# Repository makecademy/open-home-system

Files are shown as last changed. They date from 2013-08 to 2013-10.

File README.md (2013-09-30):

open-home-system
================

Repository for the Open Home System (OHS) modules & software. The repository is organized as following:

- Hardware: all the devices included in the Open Home System. For each device, you will find Arduino sketches (to test the module & connect it to the whole system) and 3D files for the cases.
The folder common contains the common files used for Open Home System, like the Arduino library, the primitives for the cases, and the schematic & layout for the Open Home System board.

- Software: all the software you need to run Open Home System.

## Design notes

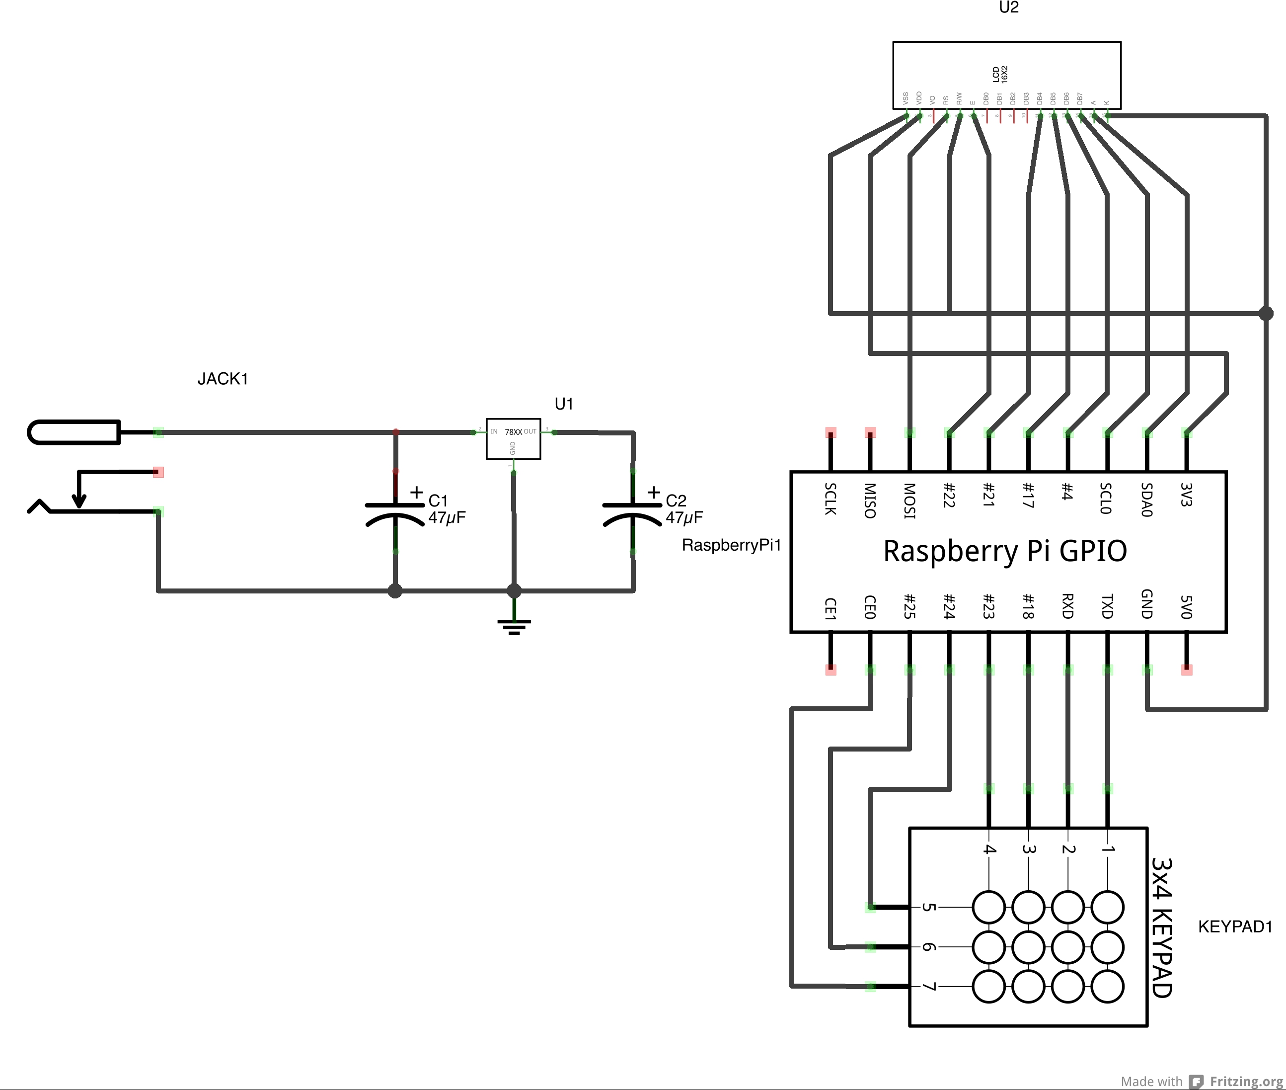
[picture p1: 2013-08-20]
hardware/base/pcb/base_station_schem.jpg

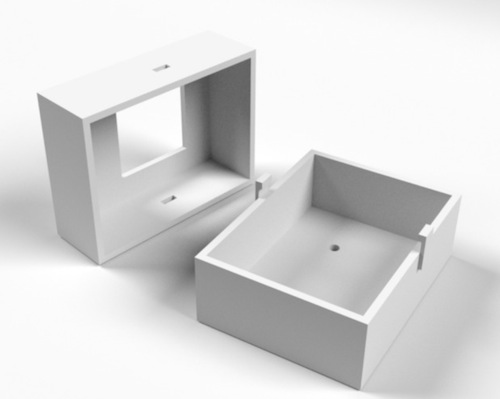
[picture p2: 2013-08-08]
hardware/motion/case/render.jpg

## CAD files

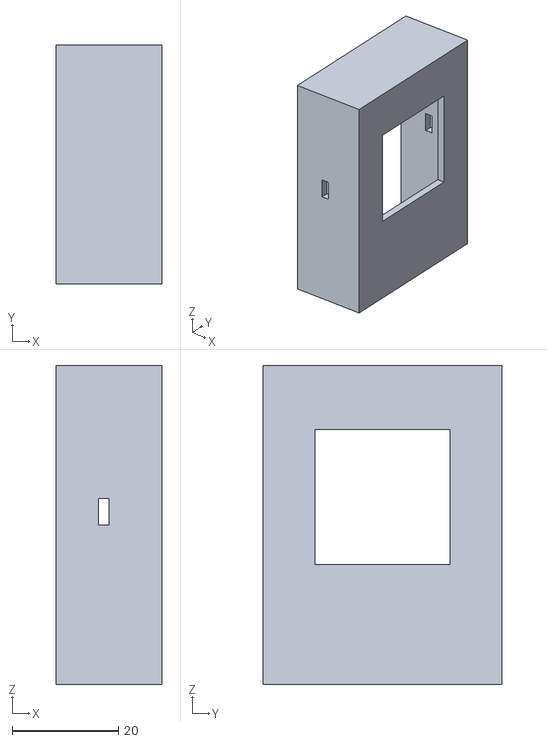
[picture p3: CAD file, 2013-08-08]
hardware/motion/case/motion_front.stl
20.0 x 45.0 x 60.0

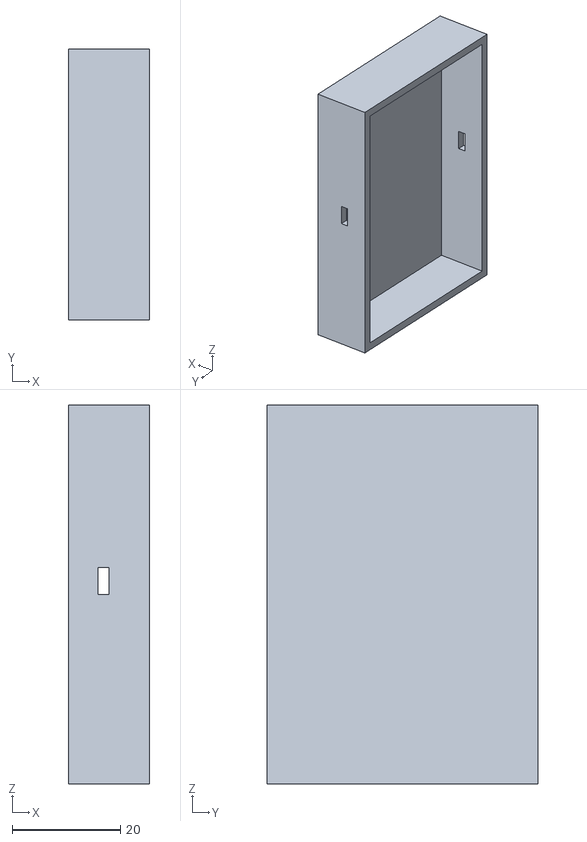
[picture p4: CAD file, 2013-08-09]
hardware/temperature/case/temperature_front.stl
15.0 x 50.0 x 70.0

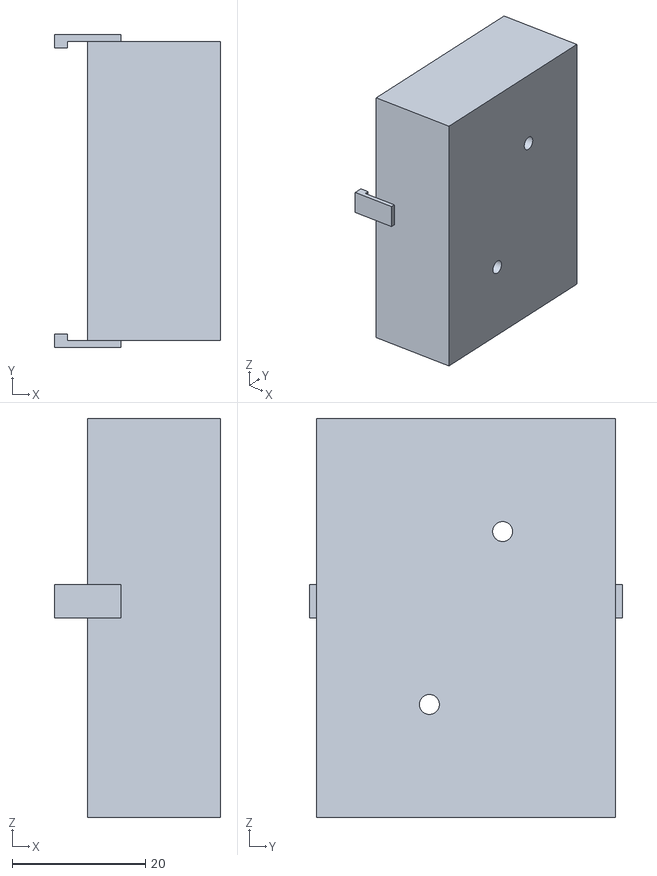
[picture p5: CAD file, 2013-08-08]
hardware/motion/case/motion_back.stl
25.0 x 47.0 x 60.0

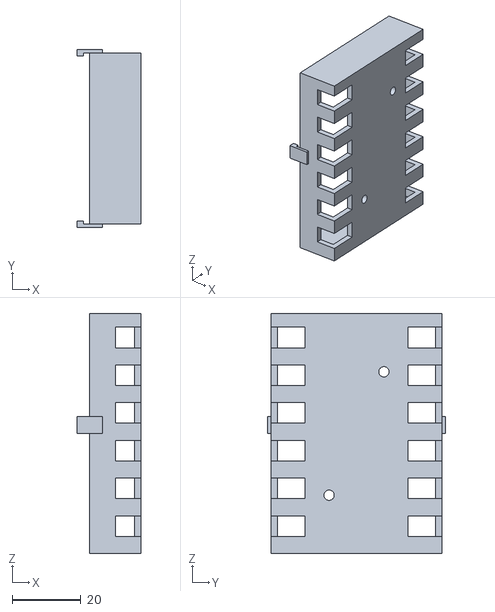
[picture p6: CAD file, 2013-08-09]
hardware/temperature/case/temperature_back.stl
18.8 x 52.0 x 70.0

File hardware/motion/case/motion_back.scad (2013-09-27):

// Use common library
use <../../common/primitives.scad>;

// Parameters

// Main box
w = 60;
l = 60;
h = 15;
thickness = 2; 

// Batteries
battery_h = 49;
battery_r = 7;
number_batteries = 3;
draw_batteries = 1;

// Holes
fixation_hole_r = 1.5;
distance_from_edges = 15;

// Attach
attach_clip_h = 1;
attach_clip_l = 2;
attach_l = 2*(5+attach_clip_l);
attach_w = 5;
attach_h = 1;


// Back box
difference(){

	case(h, w, l, thickness);

	case_hole(distance_from_edges,distance_from_edges, fixation_hole_r);
	case_hole(w-distance_from_edges,l-distance_from_edges, fixation_hole_r);

}

// Attach
translate([-attach_l/2,-attach_h,l/2]) cube([attach_l,attach_h,attach_w]);
translate([-attach_l/2,0,l/2]) cube([attach_clip_l,attach_clip_h,attach_w]);

translate([-attach_l/2,w,l/2]) cube([attach_l,attach_h,attach_w]);
translate([-attach_l/2,w-attach_h,l/2]) cube([attach_clip_l,attach_clip_h,attach_w]);

// Batteries
if (draw_batteries == 1) {
	batteries(w,l,6,battery_r, battery_h, number_batteries);
}

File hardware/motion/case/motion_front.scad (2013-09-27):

// Use common library
use <../../common/primitives.scad>;

// Parameters

// Main box
w = 60;
l = 60;
h = 22;
thickness = 2; 
pcb_attach_h = 12;
draw_box = 1;

// PCB
pcb_width = 50;
pcb_length = 50;
pcb_thickness = 10;
pcb_hole = 1;
pcb_hole_distance = 3.5;
draw_pcb = 1;

// Sensor
sensor_w = 24; 
sensor_l = 24;
sensor_t = 3;
sensor_pcb_w = 24;
sensor_pcb_l = 32;
sensor_pcb_t = 7;
sensor_pcb_hole = 1;
sensor_attach_h = 6;
distance_from_top = 10;
draw_sensor = 0;

// Clips
attach_clip_w = 5;
attach_clip_l = 2;
distance_from_edge = 5;

// Front box
if (draw_box == 1){
	difference(){

		case(h, w, l, thickness);

		// Sensor hole
		translate([1,w/2-sensor_w/2,l-thickness-distance_from_top-sensor_l]) {
				cube([50,sensor_w,sensor_l]);
			} 

		// Clips on the sides
		translate([distance_from_edge,-5,l/2]) {
			cube([attach_clip_l,100,attach_clip_w]);
		} 
	
	}

}

// PCB attaches
pcb_attaches(w,l,h,pcb_length,pcb_width,pcb_hole,pcb_hole_distance,pcb_attach_h);

// PCB
if (draw_pcb == 1){
	pcb(5,5,10,pcb_width,pcb_length,pcb_thickness,pcb_hole,pcb_hole_distance);
}	

// Sensor attaches
rotate([0,-90,0]){
		translate([l-thickness - distance_from_top-sensor_l/2, (w-sensor_pcb_l)/2 + (sensor_pcb_l-sensor_l)/4,-h]) {
			difference(){
				cylinder(h = sensor_attach_h, r=1.5*sensor_pcb_hole, $fn=50);
				translate([0,0,-sensor_attach_h/2]){
					cylinder(h = 20, r=sensor_pcb_hole, $fn=50);
				}
			}
		}

		translate([l-thickness - distance_from_top-sensor_l/2, w - ((w-sensor_pcb_l)/2 + (sensor_pcb_l-sensor_l)/4) ,-h]) {
			difference(){
				cylinder(h = sensor_attach_h, r=1.5*sensor_pcb_hole, $fn=50);
				translate([0,0,-sensor_attach_h/2]){
					cylinder(h = 20, r=sensor_pcb_hole, $fn=50);
				}
			}
		}
}


// Sensor
if (draw_sensor == 1) {
	translate([20,w/2-sensor_w/2,l-thickness-distance_from_top-sensor_l]){
		rotate([0,-90,0]){

			// Sensor body
			cube([sensor_w,sensor_l,sensor_t]);
			translate([0,-(sensor_pcb_l-sensor_l)/2,sensor_t]){

				// Sensor PCB
				difference(){
					cube([sensor_pcb_w,sensor_pcb_l,sensor_pcb_t]);
					translate([sensor_pcb_w/2,(sensor_pcb_l-sensor_l)/4,-5]){
						cylinder(h = 20, r=sensor_pcb_hole, $fn=50);
					}
					translate([sensor_pcb_w/2,sensor_pcb_l - (sensor_pcb_l-sensor_l)/4,-5]){
						cylinder(h = 20, r=sensor_pcb_hole, $fn=50);
					}
				}
				
			}
		}
	}
}

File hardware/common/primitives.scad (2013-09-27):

// Module case
module case(h, w, l, t) {
    difference(){
		cube([h,w,l]);
		translate([-t,t,t]) {
  			cube([h,w-2*t,l-2*t]);
		}
	}
}

// Module holes
module case_hole(edge_distance_w ,edge_distance_l, hole_radius) {
    translate([0,edge_distance_w,edge_distance_l]) {
		rotate([0,90,0]){
			cylinder(h = 30, r=hole_radius, $fn=50);
		} 
	}
}

// PCB
module pcb(translation_w,translation_l,translation_h,pcb_width,pcb_length,pcb_thickness,pcb_hole_radius,pcb_hole_distance) 
{		
	translate([translation_h,translation_w,translation_l]){
		rotate([0,-90,0]){
	difference(){
		cube([pcb_width,pcb_length,pcb_thickness]);
		translate([pcb_hole_distance,pcb_hole_distance,-10]) {
			cylinder(h = 30, r=pcb_hole_radius, $fn=50);
		}
		translate([pcb_width-pcb_hole_distance,pcb_length-pcb_hole_distance,-10]) {
			cylinder(h = 30, r=pcb_hole_radius, $fn=50);
		}
	}
	}
	}
}

// PCB attaches
module pcb_attaches(case_w,case_l,case_h,pcb_length,pcb_width,pcb_hole_radius,pcb_hole_distance,pcb_attach_h){
	rotate([0,-90,0]){
		translate([(case_w-pcb_length)/2 + pcb_hole_radius + pcb_hole_distance, (case_l-pcb_width)/2 + pcb_hole_distance - pcb_hole_radius,-case_h]) {
			difference(){
				cylinder(h = pcb_attach_h, r=2*pcb_hole_radius, $fn=50);
				translate([0,0,pcb_attach_h/2]){
					cylinder(h = 10, r=pcb_hole_radius, $fn=50);
				}
			}
		}

		translate([case_l-pcb_hole_distance - (case_w-pcb_length)/2 - pcb_hole_radius,case_w-pcb_hole_distance-(case_l-pcb_width)/2 + pcb_hole_radius,-case_h]) {
			difference(){
				cylinder(h = pcb_attach_h, r=2*pcb_hole_radius, $fn=50);
				translate([0,0,pcb_attach_h/2]){
					cylinder(h = 10, r=pcb_hole_radius, $fn=50);
				}
			}
		}
	}
}

// PCB attach
module pcb_attach(translation_w,translation_l,case_h,pcb_length,pcb_width,pcb_hole_radius,pcb_hole_distance,pcb_attach_h){
	rotate([0,-90,0]){
		translate([translation_w + pcb_hole_radius + pcb_hole_distance, translation_l + pcb_hole_distance - pcb_hole_radius,-case_h]) {
			difference(){
				cylinder(h = pcb_attach_h, r=2*pcb_hole_radius, $fn=50);
				translate([0,0,pcb_attach_h/2]){
					cylinder(h = 10, r=pcb_hole_radius, $fn=50);
				}
			}
		}

		translate([translation_w + pcb_width - pcb_hole_distance,translation_l + pcb_length - pcb_hole_distance,-case_h]) {
			difference(){
				cylinder(h = pcb_attach_h, r=2*pcb_hole_radius, $fn=50);
				translate([0,0,pcb_attach_h/2]){
					cylinder(h = 10, r=pcb_hole_radius, $fn=50);
				}
			}
		}
	}
}

// Batteries
module batteries(w,l,translation,battery_r, battery_h, number_batteries){
	for ( i = [0 : number_batteries - 1] ){
		translate([translation,battery_r + (w-6*battery_r)/2+i*battery_r*2,(l-battery_h)/2]){
			cylinder(h = battery_h, r=battery_r, $fn=50);
		}
	}
}

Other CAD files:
hardware/base/case/base_back.scad
hardware/relay/case/relay_back.scad
hardware/relay/case/relay_front.scad
hardware/temperature/case/temperature_back.scad
hardware/temperature/case/temperature_front.scad

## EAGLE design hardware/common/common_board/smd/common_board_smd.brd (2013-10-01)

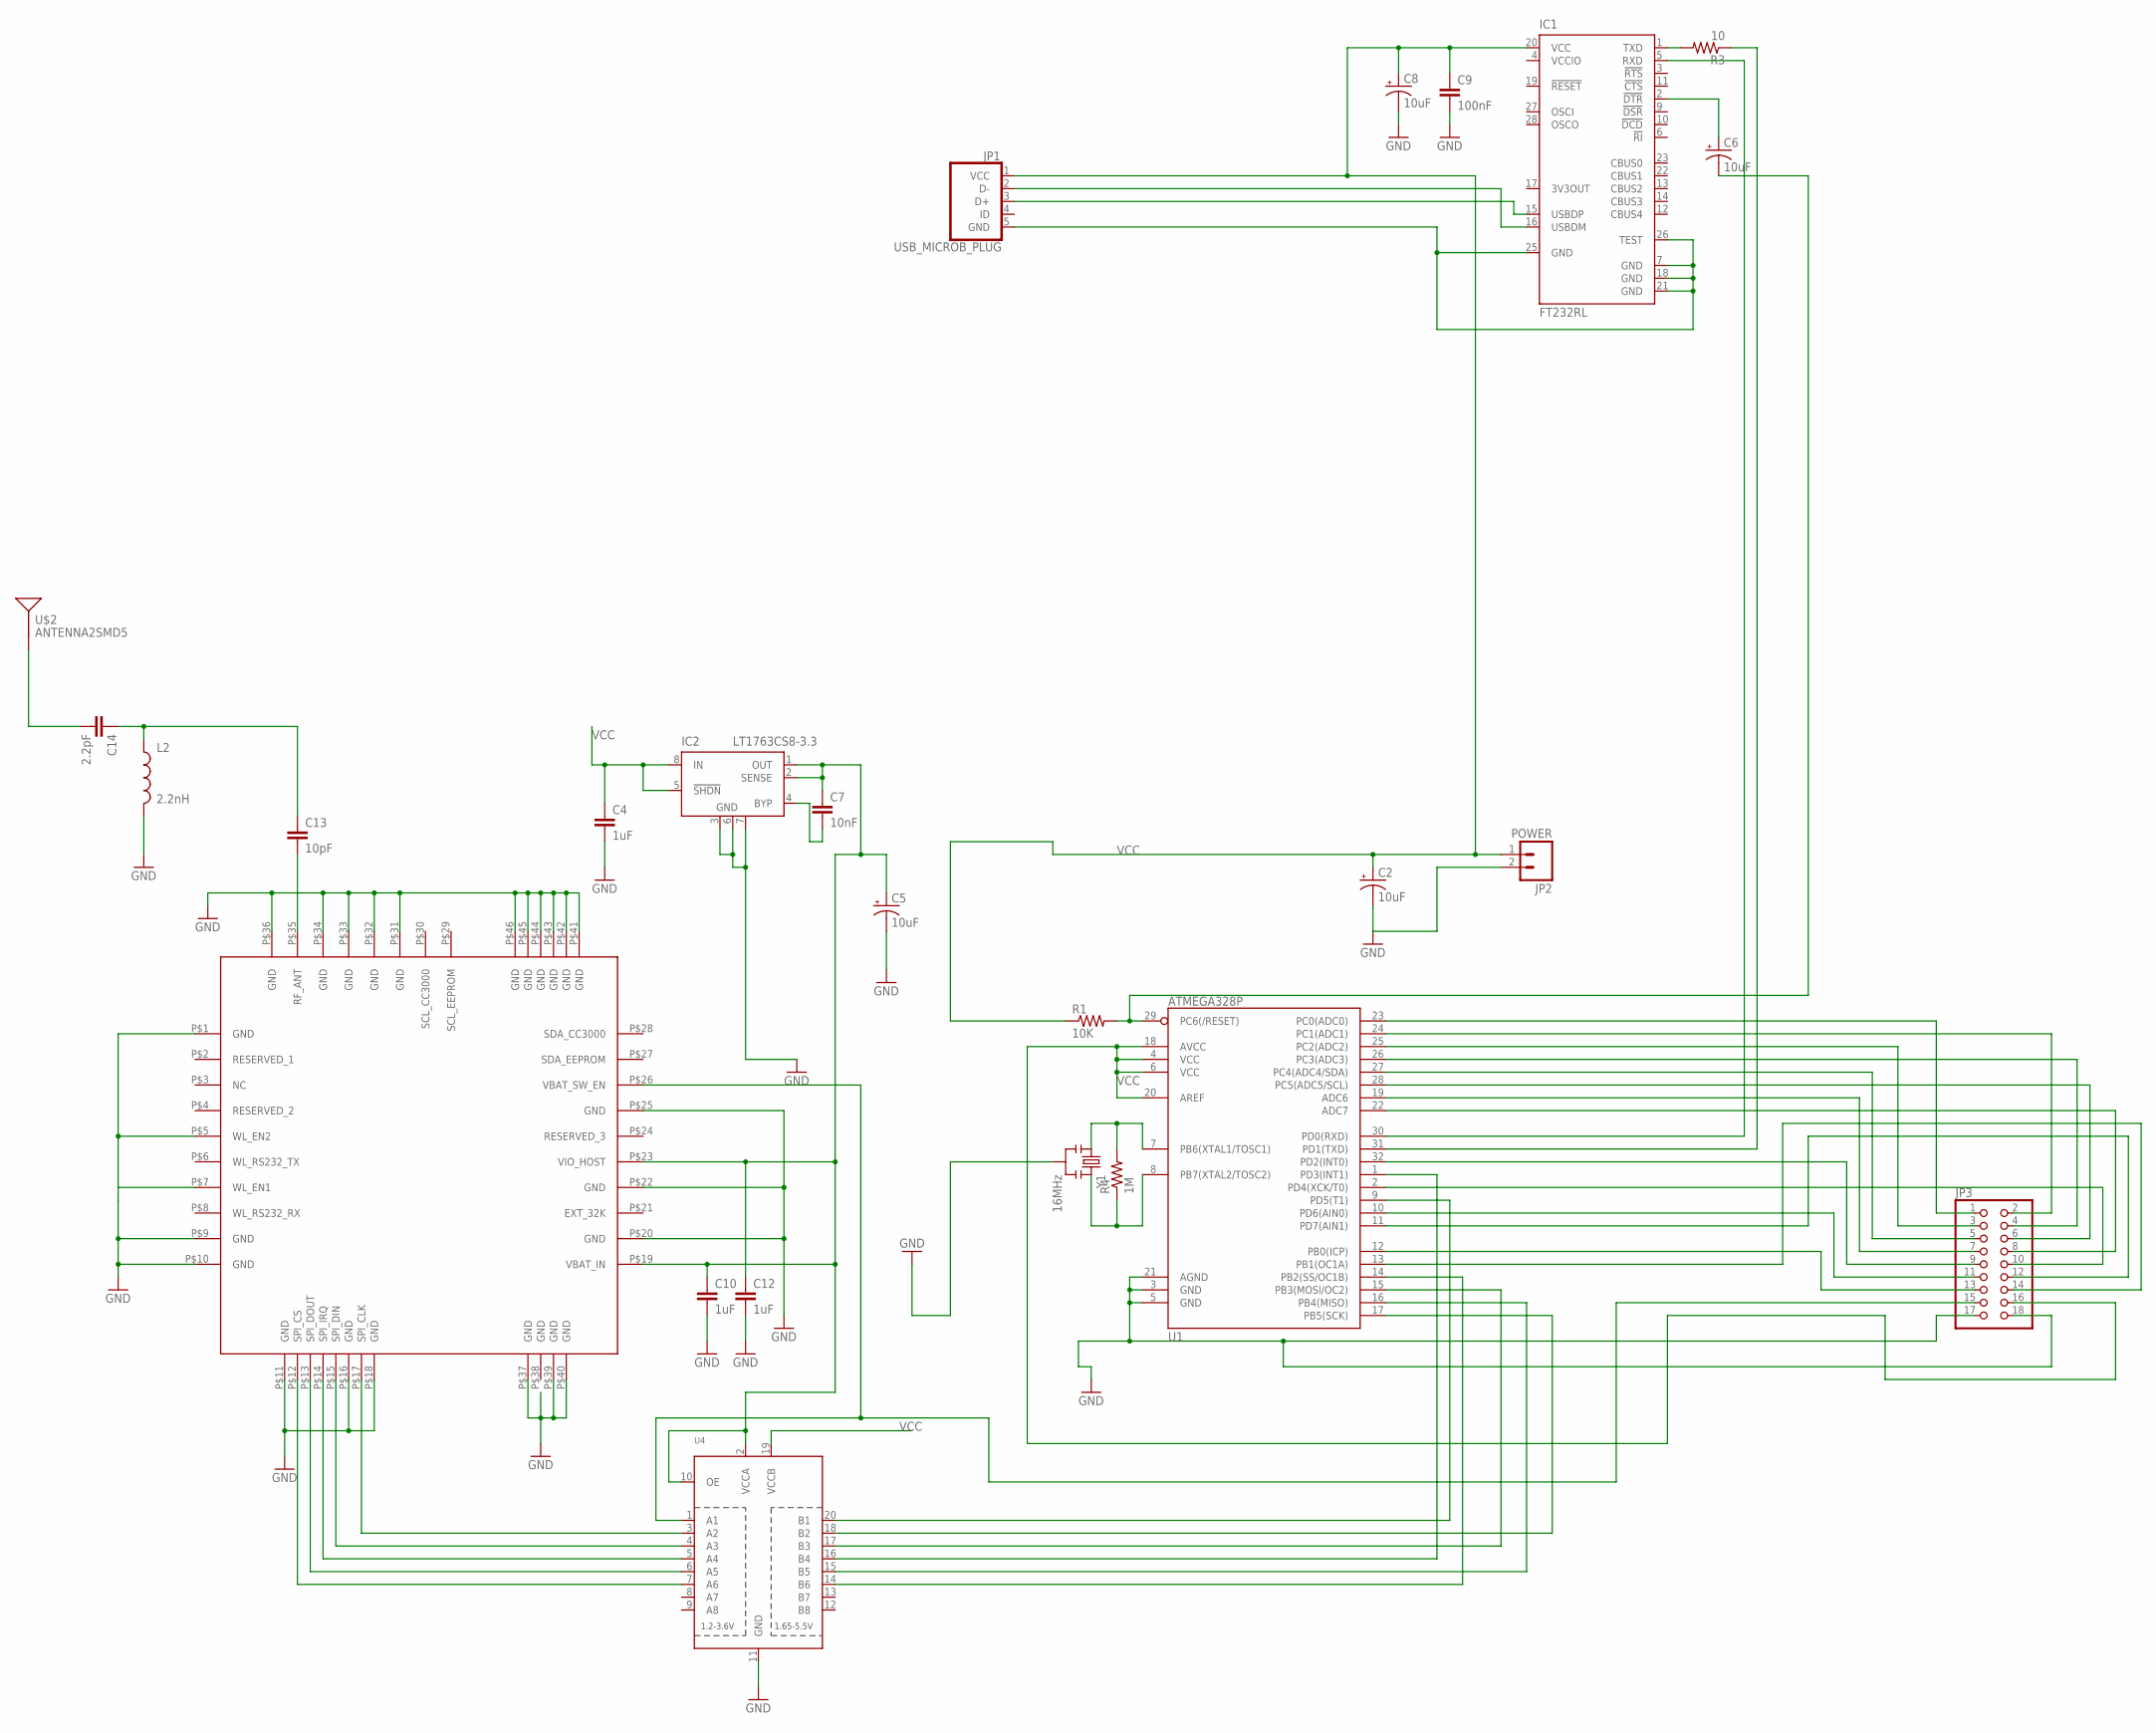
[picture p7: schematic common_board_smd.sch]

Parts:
C2, C6, C8: 10uF; EIA3216
C4: 1uF; 0805
C5: 10uF; EIA3528
C7: 10nF; 0805
C9: 100nF; 0805
C10, C12: 1uF; 1206
C13: 10pF; 0805
C14: 2.2pF; 0805
IC1: FT232RL; SSOP28
IC2: LT1763CS8-3.3; SOIC8
JP1: USB_MICROB_PLUG; MICRO-B-RA-SMT
JP2: POWER; 1X02
JP3: PINHD-2X9-BIG; 2X09-BIG
L2: 2.2nH; 0805
R1: 10K; 0805
R3: 10; 0805
R4: 1M; 0603-RES
U1: ATMEGA328P; TQFP32-08
U4: TXB0108PWR; TSSOP20
U$1: CC3000
U$2: ANTENNA2SMD5; ANTENNA-CHIP5
Y1: 16MHz; RESONATOR-SMD

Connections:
GND: C2.C (-), C4.2, C5.C (-), C8.C (-), C9.2, C10.2, C12.2, IC2.3 (GND), IC2.6 (GND), IC2.7 (GND), JP2.2, JP3.17, JP3.18, L2.2, U1.3 (GND), U1.5 (GND), U1.21 (AGND), U4.11 (GND), U$1.P$1 (GND), U$1.P$5 (WL_EN2), U$1.P$7 (WL_EN1), U$1.P$9 (GND), U$1.P$10 (GND), U$1.P$11 (GND), U$1.P$16 (GND), U$1.P$18 (GND), U$1.P$20 (GND), U$1.P$22 (GND), U$1.P$25 (GND), U$1.P$31 (GND), U$1.P$32 (GND), U$1.P$33 (GND), U$1.P$34 (GND), U$1.P$36 (GND), U$1.P$37 (GND), U$1.P$39 (GND), U$1.P$40 (GND), U$1.P$41 (GND), U$1.P$42 (GND), U$1.P$43 (GND), U$1.P$44 (GND), U$1.P$45 (GND), U$1.P$46 (GND), Y1.2
unnamed: U1.9 (PD5(T1)), U4.20 (B1)
unnamed: U1.1 (PD3(INT1)), U4.16 (B4)
unnamed: C6.C (-), R1.2, U1.29 (PC6(/RESET))
unnamed: R4.2, U1.7 (PB6(XTAL1/TOSC1)), Y1.1
unnamed: U1.17 (PB5(SCK)), U4.18 (B2)
unnamed: U1.14 (PB2(SS/OC1B)), U4.14 (B6)
unnamed: JP3.14, U1.13 (PB1(OC1A))
unnamed: C5.A (+), C7.1, C10.1, C12.1, IC2.1 (OUT), IC2.2 (SENSE), U4.2 (VCCA), U4.10 (OE), U$1.P$19 (VBAT_IN), U$1.P$23 (VIO_HOST)
unnamed: U4.7 (A6), U$1.P$12 (SPI_CS)
unnamed: U4.6 (A5), U$1.P$13 (SPI_DOUT)
unnamed: U4.5 (A4), U$1.P$14 (SPI_IRQ)
unnamed: U4.4 (A3), U$1.P$15 (SPI_DIN)
unnamed: U4.3 (A2), U$1.P$17 (SPI_CLK)
unnamed: JP3.15, U4.1 (A1), U$1.P$26 (VBAT_SW_EN)
unnamed: IC1.1 (TXD), R3.2
unnamed: C13.2, U$1.P$35 (RF_ANT)
unnamed: C13.1, C14.1, L2.1
unnamed: C14.2, U$2.FEED
unnamed: U1.16 (PB4(MISO)), U4.15 (B5)
unnamed: U1.15 (PB3(MOSI/OC2)), U4.17 (B3)
unnamed: JP3.9, U1.32 (PD2(INT0))
unnamed: JP3.13, U1.12 (PB0(ICP))
unnamed: JP3.3, U1.25 (PC2(ADC2))
unnamed: JP3.8, U1.22 (ADC7)
unnamed: JP3.1, U1.23 (PC0(ADC0))
unnamed: JP3.12, U1.11 (PD7(AIN1))
unnamed: JP3.2, U1.24 (PC1(ADC1))
unnamed: IC1.15 (USBDP), JP1.3 (D+)
unnamed: IC1.16 (USBDM), JP1.2 (D-)
unnamed: R3.1, U1.31 (PD1(TXD))
unnamed: IC1.5 (RXD), U1.30 (PD0(RXD))
unnamed: C6.A (+), IC1.2 (!DTR)
unnamed: JP3.4, U1.26 (PC3(ADC3))
unnamed: JP3.5, U1.27 (PC4(ADC4/SDA))
unnamed: JP3.6, U1.28 (PC5(ADC5/SCL))
unnamed: JP3.7, U1.19 (ADC6)
unnamed: JP3.10, U1.2 (PD4(XCK/T0))
unnamed: IC1.7 (GND), IC1.18 (GND), IC1.21 (GND), IC1.25 (GND), IC1.26 (TEST), JP1.5 (GND)
unnamed: R4.1, U1.8 (PB7(XTAL2/TOSC2)), Y1.3
unnamed: C7.2, IC2.4 (BYP)
unnamed: JP3.11, U1.10 (PD6(AIN0))
SCL_CC3000: U$1.P$30 (SCL_CC3000)
SCL_EEPROM: U$1.P$29 (SCL_EEPROM)
VCC: C2.A (+), C4.1, C8.A (+), C9.1, IC1.20 (VCC), IC2.5 (!SHDN), IC2.8 (IN), JP1.1 (VCC), JP2.1, JP3.16, R1.1, U1.4 (VCC), U1.6 (VCC), U1.18 (AVCC), U1.20 (AREF), U4.19 (VCCB)
VCCIO: IC1.4 (VCCIO)

Board: 2 copper layers, 25 parts (0 on the bottom side), 43 nets, no tracks yet.

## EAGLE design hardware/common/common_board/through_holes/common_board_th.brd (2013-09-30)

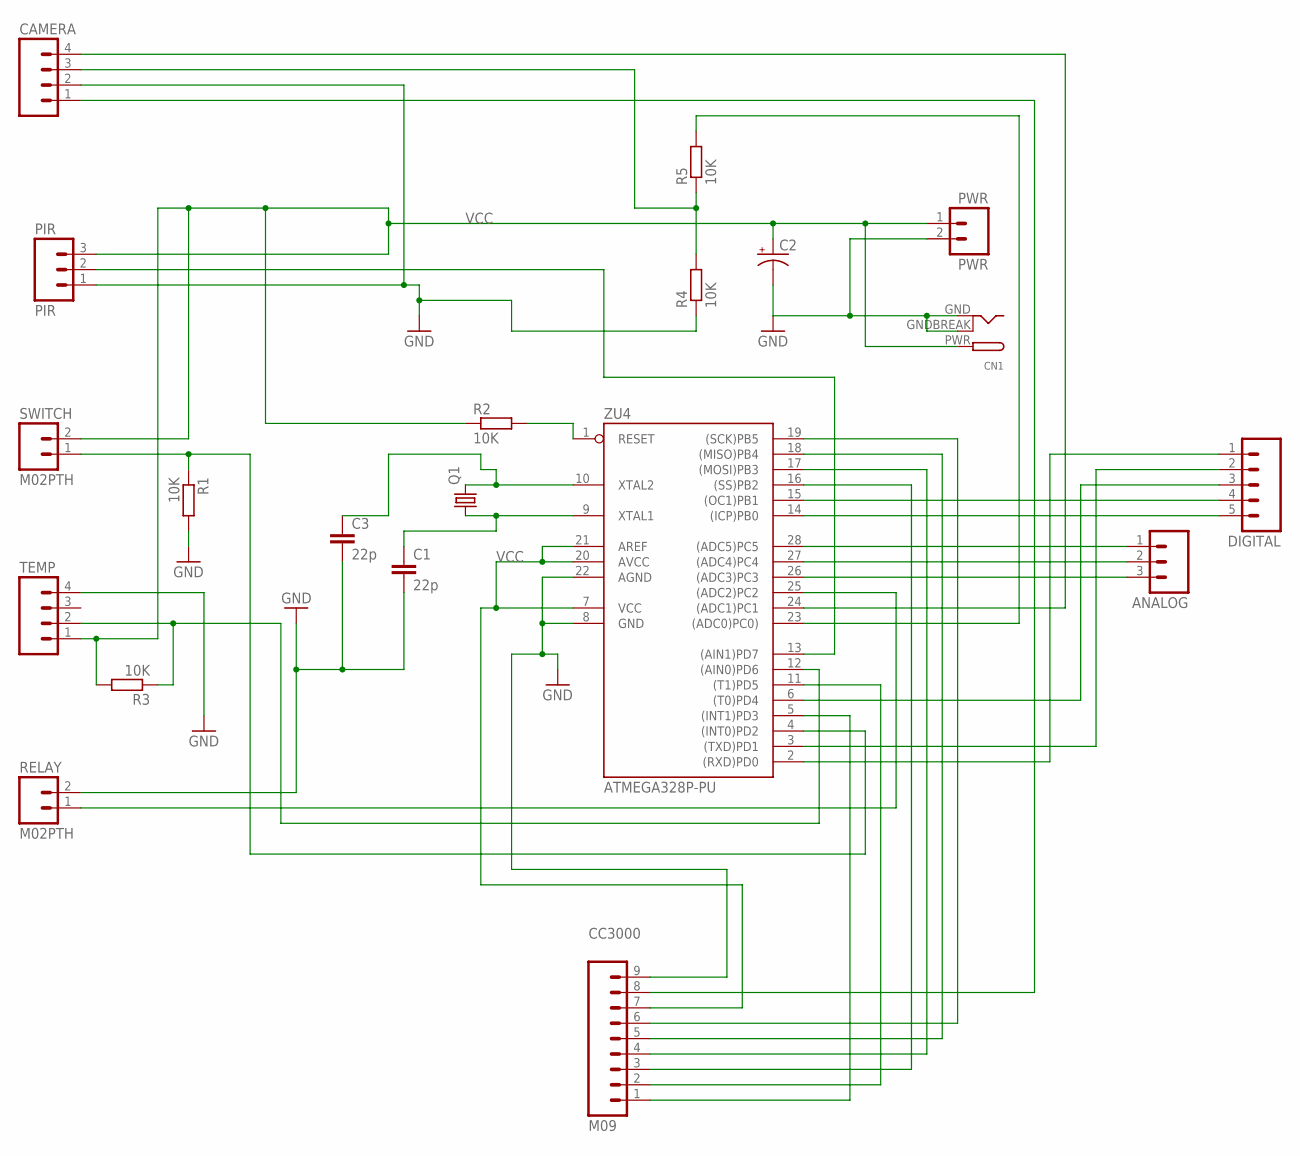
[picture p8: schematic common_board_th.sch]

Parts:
ANALOG: M03PTH; 1X03
C1, C3: 22p; C050-025X075
C2: CAP_POLPTH1; CPOL-RADIAL-100UF-25V
CAMERA: M04PTH; 1X04
CC3000: M09; 1X09
CN1: DCBARRELPTH; DCJACK_2MM_PTH
DIGITAL: M05PTH; 1X05
PIR: PIR; 1X03
PWR: PWR; 1X02
Q1: CRYSTALHC49S; HC49/S
R1, R2, R3, R4, R5: 10K; 0207/7
RELAY: M02PTH; 1X02
SWITCH: M02PTH; 1X02
TEMP: M04PTH; 1X04
ZU4: ATMEGA328P-PU; DIL28-3

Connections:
GND: C1.2, C2.2 (-), C3.2, CAMERA.2, CC3000.9, CN1.GND, CN1.GNDBREAK, PIR.1, PWR.2, R1.2, R4.1, RELAY.2, TEMP.4, ZU4.8 (GND), ZU4.22 (AGND)
unnamed: CC3000.2, ZU4.11 ((T1)PD5)
unnamed: CC3000.1, ZU4.5 ((INT1)PD3)
unnamed: R2.2, ZU4.1 (RESET)
unnamed: C1.1, Q1.1, ZU4.9 (XTAL1)
unnamed: CC3000.6, ZU4.19 ((SCK)PB5)
unnamed: CC3000.3, ZU4.16 ((SS)PB2)
unnamed: R1.1, SWITCH.1, ZU4.4 ((INT0)PD2)
unnamed: RELAY.1, ZU4.25 ((ADC2)PC2)
unnamed: R3.1, TEMP.2, ZU4.12 ((AIN0)PD6)
unnamed: ANALOG.1, ZU4.28 ((ADC5)PC5)
unnamed: CAMERA.1, CC3000.8
unnamed: CAMERA.4, ZU4.24 ((ADC1)PC1)
unnamed: CAMERA.3, R4.2, R5.1
unnamed: ANALOG.2, ZU4.27 ((ADC4)PC4)
unnamed: R5.2, ZU4.23 ((ADC0)PC0))
unnamed: ANALOG.3, ZU4.26 ((ADC3)PC3)
unnamed: DIGITAL.4, ZU4.15 ((OC1)PB1)
unnamed: DIGITAL.5, ZU4.14 ((ICP)PB0)
unnamed: CC3000.5, ZU4.18 ((MISO)PB4)
unnamed: CC3000.4, ZU4.17 ((MOSI)PB3)
unnamed: DIGITAL.3, ZU4.6 ((T0)PD4)
unnamed: DIGITAL.2, ZU4.3 ((TXD)PD1)
unnamed: DIGITAL.1, ZU4.2 ((RXD)PD0)
unnamed: PIR.2, ZU4.13 ((AIN1)PD7)
VCC: C2.1 (+), CC3000.7, CN1.PWR, PIR.3, PWR.1, R2.1, R3.2, SWITCH.2, TEMP.1, ZU4.7 (VCC), ZU4.20 (AVCC), ZU4.21 (AREF)
XTAL2: C3.1, Q1.2, ZU4.10 (XTAL2)

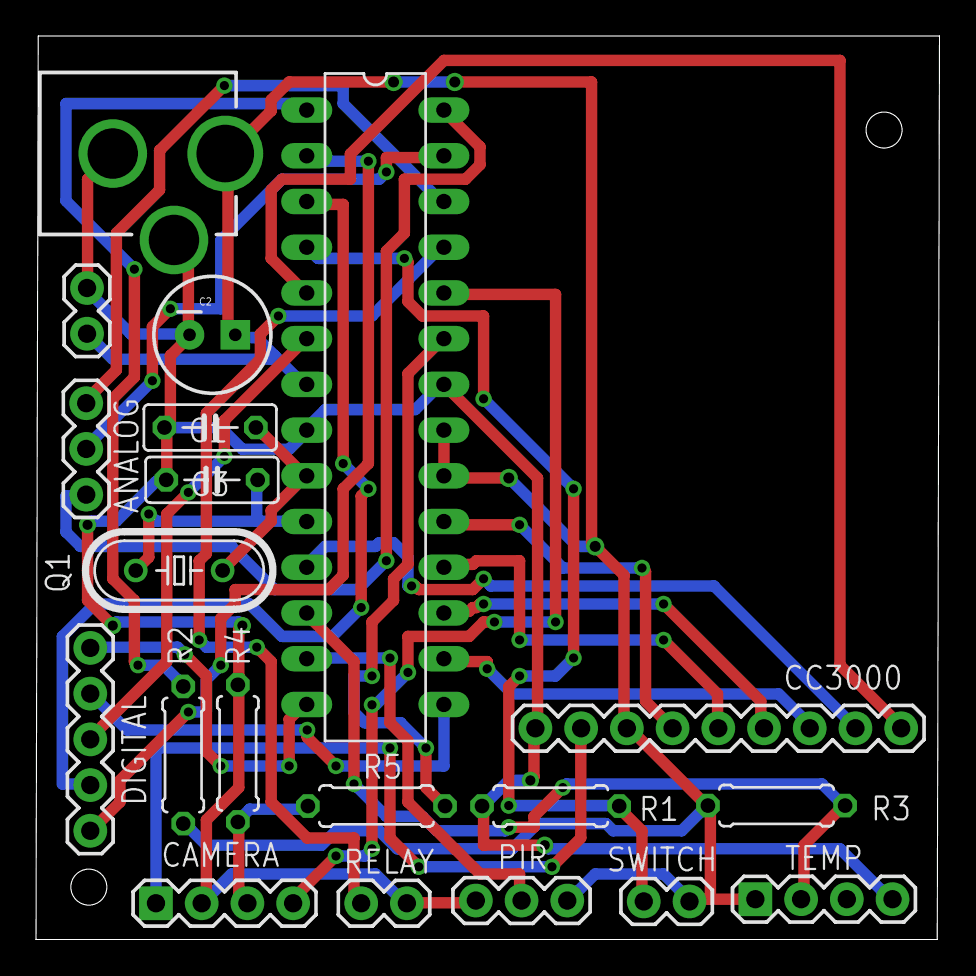
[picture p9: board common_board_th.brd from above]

Board: 2 copper layers, 50.2 x 50.2 mm, 20 parts (0 on the bottom side), 27 nets.

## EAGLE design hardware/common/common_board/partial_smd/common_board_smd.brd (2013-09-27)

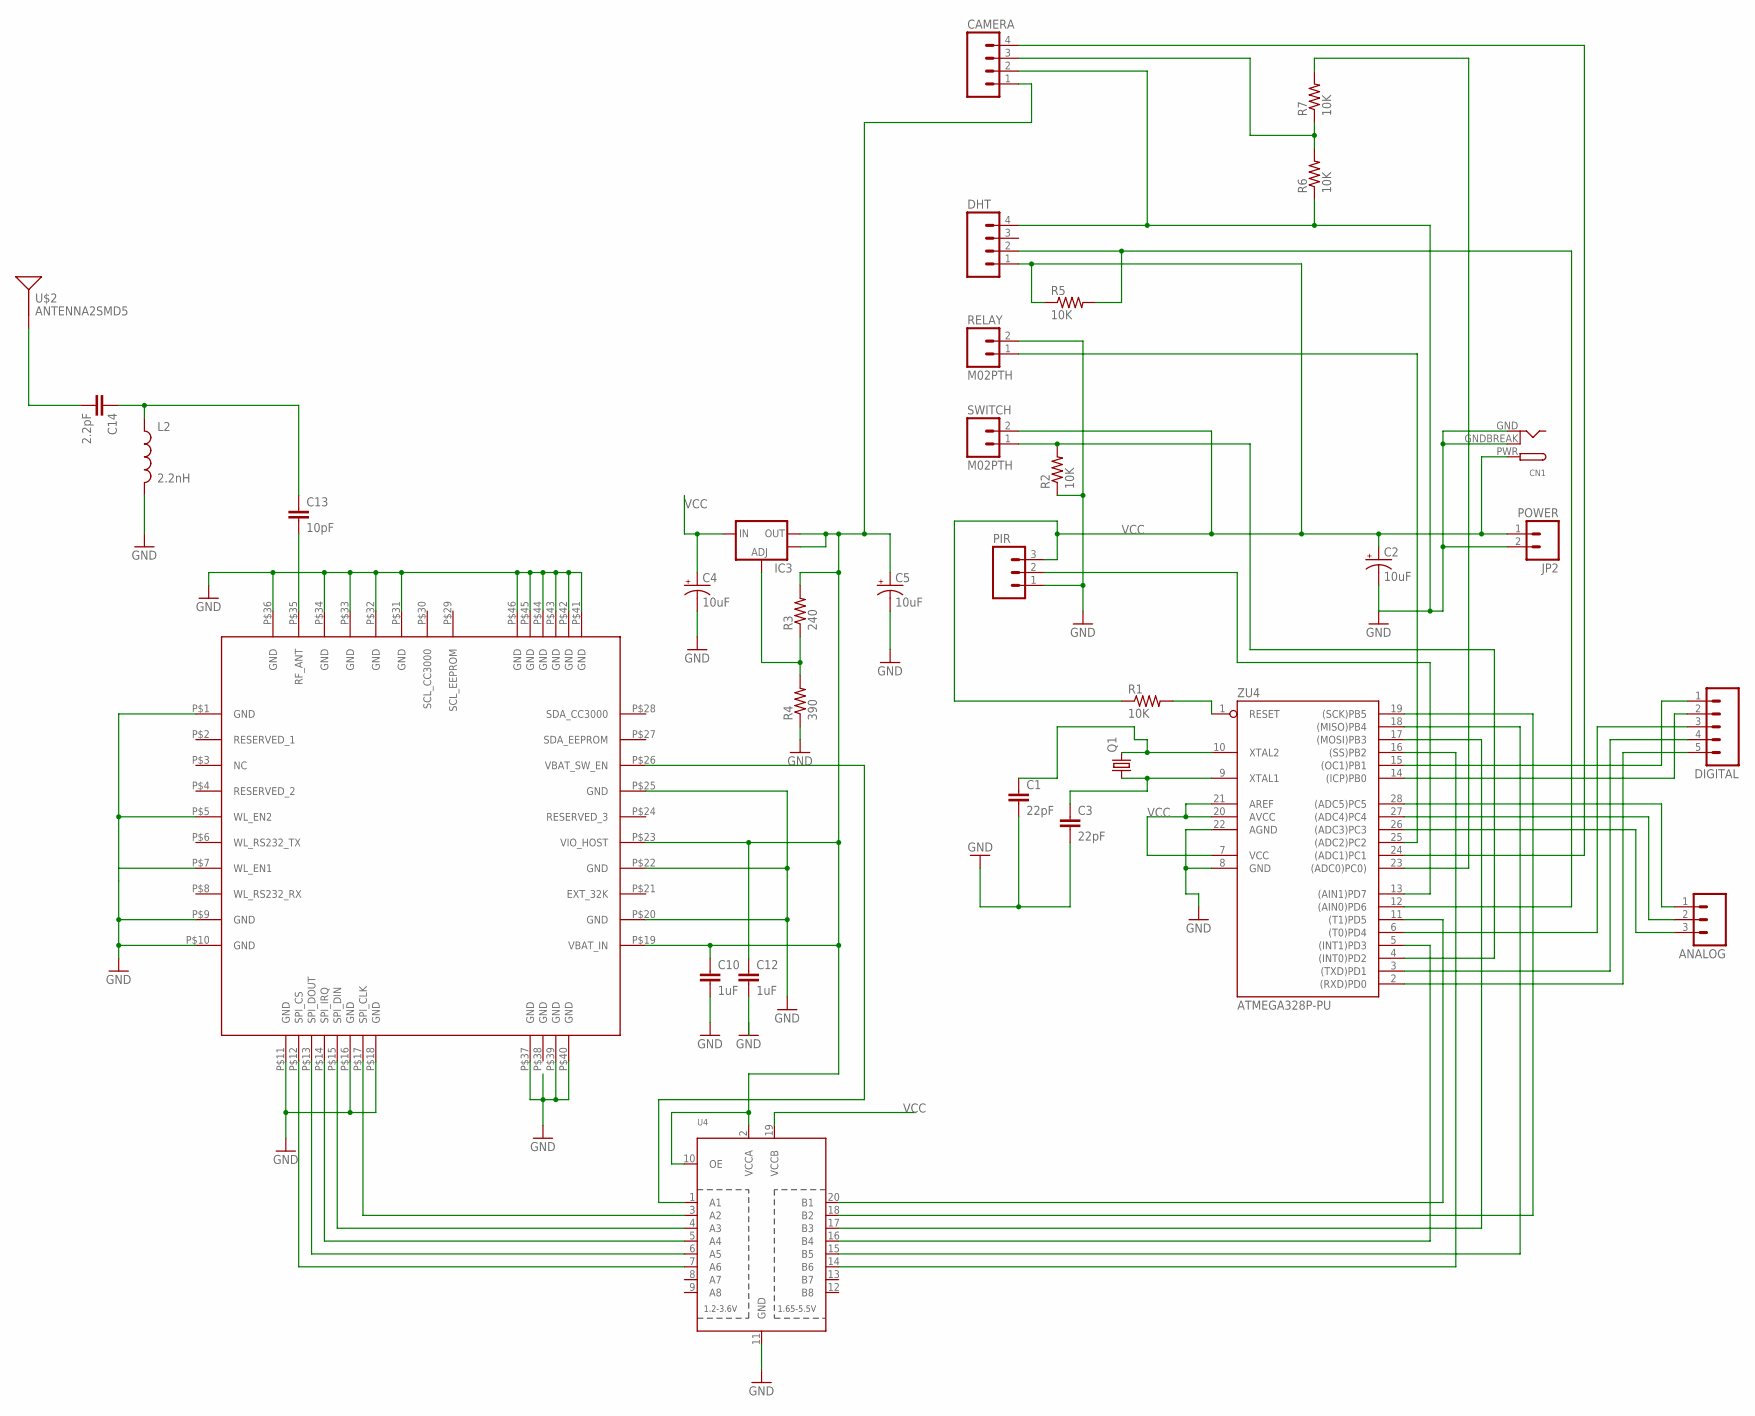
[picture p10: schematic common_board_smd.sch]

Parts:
ANALOG: M03PTH; 1X03
C1, C3: 22pF; 0805
C2: 10uF; EIA3216
C4, C5: 10uF; EIA3528
C10, C12: 1uF; 1206
C13: 10pF; 0805
C14: 2.2pF; 0805
CAMERA: M04PTH; 1X04
CN1: DCBARRELPTH; DCJACK_2MM_PTH
DHT: M04PTH; 1X04
DIGITAL: M05PTH; 1X05
IC3: V_REG_LM1117SOT223; SOT223
JP2: POWER; 1X02
L2: 2.2nH; 0805
PIR: M03PTH; 1X03
Q1: CRYSTALHC49U-V; HC49U-V
R1, R2, R5, R6, R7: 10K; 0805
R3: 240; 0805
R4: 390; 0805
RELAY: M02PTH; 1X02
SWITCH: M02PTH; 1X02
U4: TXB0108PWR; TSSOP20
U$1: CC3000
U$2: ANTENNA2SMD5; ANTENNA-CHIP5
ZU4: ATMEGA328P-PU; DIL28-3

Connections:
GND: C1.2, C2.C (-), C3.2, C4.C (-), C5.C (-), C10.2, CAMERA.2, CN1.GND, CN1.GNDBREAK, DHT.4, JP2.2, L2.2, PIR.1, R2.1, R4.1, R6.1, RELAY.2, U4.11 (GND), U$1.P$1 (GND), U$1.P$5 (WL_EN2), U$1.P$7 (WL_EN1), U$1.P$9 (GND), U$1.P$10 (GND), U$1.P$11 (GND), U$1.P$16 (GND), U$1.P$18 (GND), U$1.P$20 (GND), U$1.P$22 (GND), U$1.P$25 (GND), U$1.P$31 (GND), U$1.P$32 (GND), U$1.P$33 (GND), U$1.P$34 (GND), U$1.P$36 (GND), U$1.P$37 (GND), U$1.P$39 (GND), U$1.P$40 (GND), U$1.P$41 (GND), U$1.P$42 (GND), U$1.P$43 (GND), U$1.P$44 (GND), U$1.P$45 (GND), U$1.P$46 (GND), ZU4.8 (GND), ZU4.22 (AGND)
unnamed: U4.20 (B1), ZU4.11 ((T1)PD5)
unnamed: U4.16 (B4), ZU4.5 ((INT1)PD3)
unnamed: R1.2, ZU4.1 (RESET)
unnamed: C3.1, Q1.1, ZU4.9 (XTAL1)
unnamed: U4.18 (B2), ZU4.19 ((SCK)PB5)
unnamed: U4.14 (B6), ZU4.16 ((SS)PB2)
unnamed: C5.A (+), C10.1, C12.1, CAMERA.1, IC3.2 (OUT), IC3.4 (OUT), R3.2, U4.2 (VCCA), U4.10 (OE), U$1.P$19 (VBAT_IN), U$1.P$23 (VIO_HOST)
unnamed: U4.7 (A6), U$1.P$12 (SPI_CS)
unnamed: U4.6 (A5), U$1.P$13 (SPI_DOUT)
unnamed: U4.5 (A4), U$1.P$14 (SPI_IRQ)
unnamed: U4.4 (A3), U$1.P$15 (SPI_DIN)
unnamed: U4.3 (A2), U$1.P$17 (SPI_CLK)
unnamed: U4.1 (A1), U$1.P$26 (VBAT_SW_EN)
unnamed: IC3.1 (ADJ), R3.1, R4.2
unnamed: C13.2, U$1.P$35 (RF_ANT)
unnamed: C13.1, C14.1, L2.1
unnamed: C14.2, U$2.FEED
unnamed: U4.15 (B5), ZU4.18 ((MISO)PB4)
unnamed: U4.17 (B3), ZU4.17 ((MOSI)PB3)
unnamed: R2.2, SWITCH.1, ZU4.4 ((INT0)PD2)
unnamed: DHT.2, R5.2, ZU4.12 ((AIN0)PD6)
unnamed: RELAY.1, ZU4.25 ((ADC2)PC2)
unnamed: CAMERA.3, R6.2, R7.1
unnamed: R7.2, ZU4.23 ((ADC0)PC0))
unnamed: PIR.2, ZU4.13 ((AIN1)PD7)
unnamed: CAMERA.4, ZU4.24 ((ADC1)PC1)
unnamed: ANALOG.3, ZU4.26 ((ADC3)PC3)
unnamed: ANALOG.2, ZU4.27 ((ADC4)PC4)
unnamed: ANALOG.1, ZU4.28 ((ADC5)PC5)
unnamed: DIGITAL.5, ZU4.2 ((RXD)PD0)
unnamed: DIGITAL.4, ZU4.3 ((TXD)PD1)
unnamed: DIGITAL.3, ZU4.6 ((T0)PD4)
unnamed: DIGITAL.2, ZU4.14 ((ICP)PB0)
unnamed: DIGITAL.1, ZU4.15 ((OC1)PB1)
SCL_CC3000: U$1.P$30 (SCL_CC3000)
SCL_EEPROM: U$1.P$29 (SCL_EEPROM)
VCC: C2.A (+), C4.A (+), CN1.PWR, DHT.1, IC3.3 (IN), JP2.1, PIR.3, R1.1, R5.1, SWITCH.2, U4.19 (VCCB), ZU4.7 (VCC), ZU4.20 (AVCC), ZU4.21 (AREF)
XTAL2: C1.1, Q1.2, ZU4.10 (XTAL2)

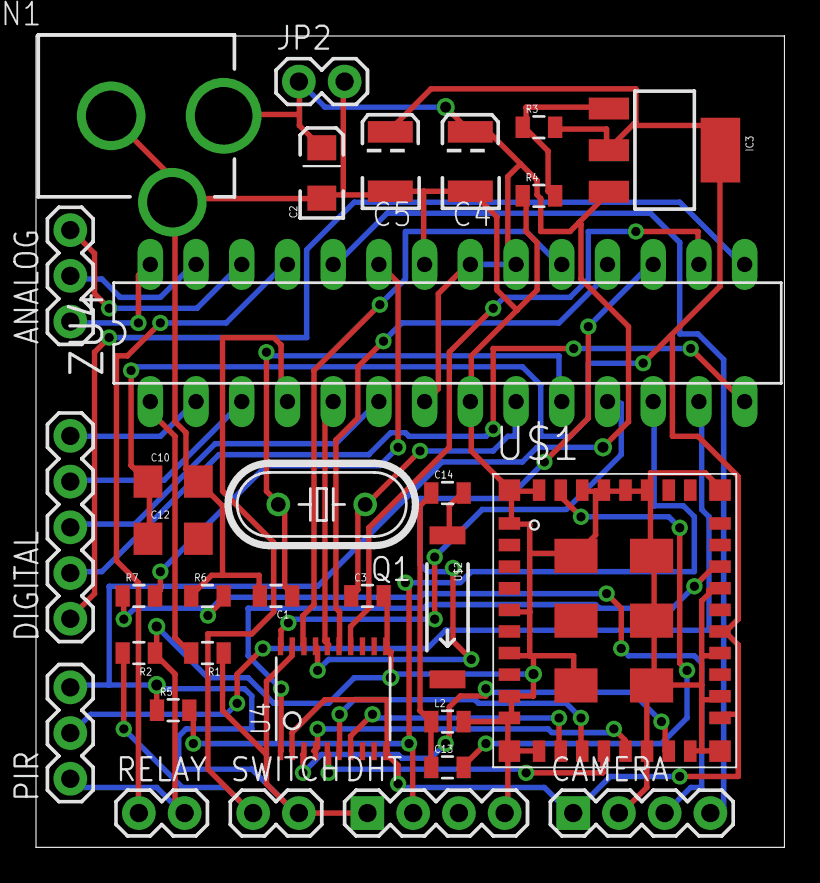
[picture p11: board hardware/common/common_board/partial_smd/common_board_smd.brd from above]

Board: 2 copper layers, 41.6 x 45.1 mm, 32 parts (0 on the bottom side), 37 nets.

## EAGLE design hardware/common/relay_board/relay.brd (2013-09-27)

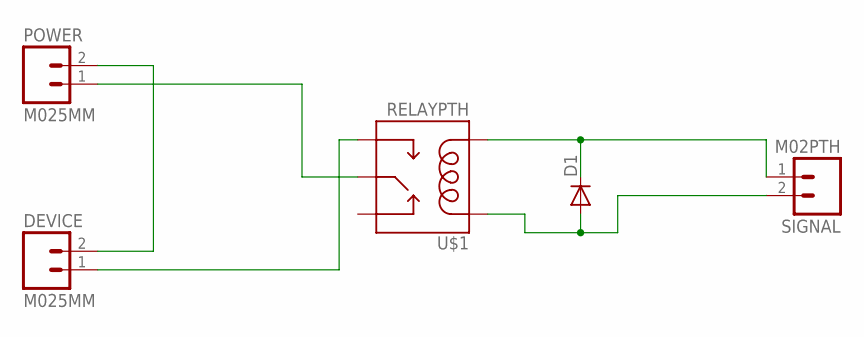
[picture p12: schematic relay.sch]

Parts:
D1: DIODE1N4148; DIODE-1N4148
DEVICE: M025MM; SCREWTERMINAL-5MM-2
POWER: M025MM; SCREWTERMINAL-5MM-2
SIGNAL: M02PTH; 1X02
U$1: RELAYPTH; RELAY-G5Q

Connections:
unnamed: D1.C, SIGNAL.1, U$1.1 (COIL2)
unnamed: D1.A, SIGNAL.2, U$1.5 (COIL1)
unnamed: POWER.1, U$1.2 (MAIN)
unnamed: DEVICE.1, U$1.3 (NO)
unnamed: DEVICE.2, POWER.2

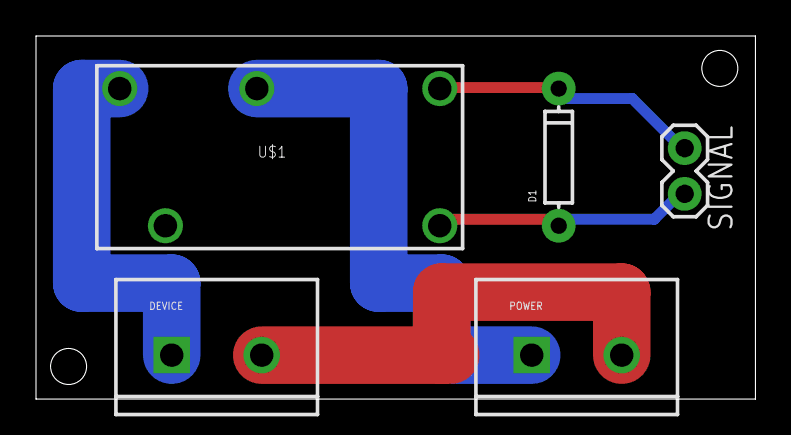
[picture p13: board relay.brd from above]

Board: 2 copper layers, 40.0 x 20.2 mm, 5 parts (0 on the bottom side), 5 nets.

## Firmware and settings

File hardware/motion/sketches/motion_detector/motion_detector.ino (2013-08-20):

/*************************************************** 
  This is the sketch to test the wireless motion detector 
  using the Parallax PIR sensor with the CC3000 WiFi chip
  
  Written by Marco Schwartz for Open Home System.
  BSD license, all text above must be included in any redistribution
 ****************************************************/

#include <Adafruit_CC3000.h>
#include <ccspi.h>
#include <SPI.h>
#include <string.h>
#include "utility/debug.h"

// Define CC3000 chip pins
#define ADAFRUIT_CC3000_IRQ   3
#define ADAFRUIT_CC3000_VBAT  5
#define ADAFRUIT_CC3000_CS    10

// WiFi network
#define WLAN_SSID       "QL2"           // cannot be longer than 32 characters!
#define WLAN_PASS       "5145246333"
// Security can be WLAN_SEC_UNSEC, WLAN_SEC_WEP, WLAN_SEC_WPA or WLAN_SEC_WPA2
#define WLAN_SECURITY   WLAN_SEC_WPA2

// Sensor pin
const int sensor_pin = 8; 

// Sensor readout
int old_sensor_value;
int sensor_value;

// Registration
boolean detected = false;
boolean registered = false;
String sensor_id = "motion1";

// Server IP
char server[] = "192.168.1.133";
int port = 8888;

// Create CC3000 object
Adafruit_CC3000 cc3000 = Adafruit_CC3000(ADAFRUIT_CC3000_CS, ADAFRUIT_CC3000_IRQ, ADAFRUIT_CC3000_VBAT,
                                         SPI_CLOCK_DIV2);
                                         
uint32_t ip = cc3000.IP2U32(192,168,1,179);

/**************************************************************************/
/*!
    @brief  Sets up the HW and the CC3000 module (called automatically
            on startup)
*/
/**************************************************************************/

void setup(void)
{
  Serial.begin(115200);
  //displayFreeRam();
  
  // Initialise the module
  Serial.println(F("\nInitializing..."));
  if (!cc3000.begin())
  {
    Serial.println(F("Couldn't begin()! Check your wiring?"));
    while(1);
  }

  // Connect to  WiFi network
  cc3000.connectToAP(WLAN_SSID, WLAN_PASS, WLAN_SECURITY);
  Serial.println(F("Connected!"));
    
  // Display connection details
  Serial.println(F("Request DHCP"));
  while (!cc3000.checkDHCP())
  {
    delay(100); // ToDo: Insert a DHCP timeout!
  }  

  while (! displayConnectionDetails()) {
    delay(1000);
  }
  
  cc3000.printIPdotsRev(ip);
  
  // Check registration status
  Serial.println("Already registered ?");
  String request = "GET /ohs/server.php?device="+ sensor_id +"&phase=registration HTTP/1.0";
  char charBuf[request.length()];
  request.toCharArray(charBuf,request.length()); 
  
  String result = send_request(charBuf);
   if(result.endsWith("Device registered"))
    {
      Serial.println("Device already registered");
      registered = true;
      detected = true;
    }
    
  // Check detection status
  if (detected == false) {
    
    Serial.println("Already detected ?");
    String request = "GET /ohs/server.php?device="+ sensor_id +"&phase=detection HTTP/1.0";
    char charBuf[request.length()];
    request.toCharArray(charBuf,request.length()); 
    
    String result = send_request(charBuf);
    if(result.endsWith("Device already detected"))
    {
      Serial.println("Device already detected");
      detected = true;
    }
  }
  
  // First readout
  int sensor_value = digitalRead(8);
  old_sensor_value = sensor_value;
  
  // End of setup
  Serial.println("Detected:");
  Serial.println(detected);
  Serial.println("Registered:");
  Serial.println(registered);
}

void loop(void)
{
  // Detection phase 
  if (registered == false && detected == false)
  {
    Serial.println("Waiting for detection");
    String request = "GET /ohs/server.php?device="+ sensor_id +"&phase=detection HTTP/1.0";
    char charBuf[request.length()];
    request.toCharArray(charBuf,request.length()); 
    
    String result = send_request(charBuf);
  
    // Sensor detected ?
    if(result.endsWith("Device detected"))
    {
      Serial.println("Device detected");
      detected = true;
    }
  
  // Retry every second
  delay(1000);

  }
  
  // Registration phase 
  if (registered == false && detected == true)
  {
    Serial.println("Waiting for registration");
    String request = "GET /ohs/server.php?device="+sensor_id+"&phase=registration HTTP/1.0";
    char charBuf[request.length()];
    request.toCharArray(charBuf,request.length()); 
    
    String result = send_request(charBuf);
  
  // Request received ?  
  if(result.endsWith("Device registered"))
    {
      Serial.println("Sensor Registered");
      registered = true;
    }
  
  // Retry every second
  delay(1000);

  }
  
  // Normal operation
  if (registered == true) {
 
    // Read sensor
    int sensor_value = digitalRead(8);
    
    // If the value didn't change, transmit nothing
    if (sensor_value == old_sensor_value) {
      delay(1000);
    }
    
    // Otherwise, connect to server to transmit data
    else {
       if (sensor_value == 1) {
          String request = "GET /ohs/server.php?device="+sensor_id+"&data=On HTTP/1.0";
          char charBuf[request.length()];
          request.toCharArray(charBuf,request.length()); 
         String result = send_request(charBuf);
       }
       else {
          String request = "GET /ohs/server.php?device="+sensor_id+"&data=Off HTTP/1.0";
          char charBuf[request.length()];
          request.toCharArray(charBuf,request.length()); 
         String result = send_request(charBuf);
       }
    
    old_sensor_value = sensor_value;
    
    }
  }
}

/**************************************************************************/
/*!
    @brief  Tries to read the IP address and other connection details
*/
/**************************************************************************/
bool displayConnectionDetails(void)
{
  uint32_t ipAddress, netmask, gateway, dhcpserv, dnsserv;
  
  if(!cc3000.getIPAddress(&ipAddress, &netmask, &gateway, &dhcpserv, &dnsserv))
  {
    Serial.println(F("Unable to retrieve the IP Address!\r\n"));
    return false;
  }
  else
  {
    Serial.print(F("\nIP Addr: ")); cc3000.printIPdotsRev(ipAddress);
    Serial.print(F("\nNetmask: ")); cc3000.printIPdotsRev(netmask);
    Serial.print(F("\nGateway: ")); cc3000.printIPdotsRev(gateway);
    Serial.print(F("\nDHCPsrv: ")); cc3000.printIPdotsRev(dhcpserv);
    Serial.print(F("\nDNSserv: ")); cc3000.printIPdotsRev(dnsserv);
    Serial.println();
    return true;
  }
}

String send_request (const char *request) {
     
    // Connect
    String result;
    
    unsigned long connect_time;
    Serial.println("\nStarting connection to server...");
    connect_time = millis();
    Adafruit_CC3000_Client www = cc3000.connectTCP(ip, 8888);
    connect_time = millis() - connect_time;
    Serial.println("Time to connect:");
    Serial.println(connect_time);
    
    // Send request
    unsigned long request_time;
    request_time = millis();
    if (www.connected()) {
      www.fastrprintln(request);      
      Serial.println("Time for one GET:");
      Serial.println(millis() - request_time);
      www.fastrprintln(F(""));
    } 
    else {
      Serial.println(F("Connection failed"));    
      return "no answer";
    }
    request_time = millis() - request_time; 
    Serial.println("Time to send request:");
    Serial.println(request_time);
    
    unsigned long answer_time;
    answer_time = millis();
    
    while (www.connected()) {
      while (www.available()) {

    // Read answer
   //uint8_t buf[64];
   // memset(buf, 0, sizeof(buf));
        char c = www.read();
       // Serial.print(c);
        result = result + c;
      }
    }
    www.close();
    answer_time = millis() - answer_time; 
    Serial.println("Time to read answer:");
    Serial.println(answer_time);
    
    // Disconnect
    // Serial.println(F("\n\nDisconnecting"));
    //cc3000.disconnect();
    
    return result;
}

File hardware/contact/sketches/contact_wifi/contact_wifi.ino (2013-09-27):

/*************************************************** 
  This is the sketch to test the contact sensor with
  the CC3000 WiFi chip
  
  Copyright Open Home Automation 2013.
  Licensed under CERN OHL v.1.2
  
  Written by Marco Schwartz for Open Home System.
 ****************************************************/
 
#include <Adafruit_CC3000.h>
#include <ccspi.h>
#include <string.h>
#include <SPI.h>
#include "utility/debug.h"
#include <ohs.h>
 
// Sensor pin
const int sensor_pin = 2; 

// Registration
boolean detected = false;
boolean registered = false;
String sensor_id = "contact1";

// Sensor status
int old_sensor_value;
int sensor_value;

// Create CC3000 instances
Adafruit_CC3000 cc3000 = Adafruit_CC3000(ADAFRUIT_CC3000_CS, ADAFRUIT_CC3000_IRQ, ADAFRUIT_CC3000_VBAT, SPI_CLOCK_DIV2);
uint32_t ip = cc3000.IP2U32(IP1,IP2,IP3,IP4);

void setup() {
  Serial.begin(115200);
  
  // Initialise the module
  cc3000Init(cc3000);
  
  // Check registration status
  Serial.println("Already registered ?");
  String request = "device="+sensor_id+"&phase=registration&end";
  String result = sendRequest(request, cc3000, ip);
  
   if(result.startsWith("Device registered"))
    {
      Serial.println("Device already registered");
      registered = true;
      detected = true;
    }
        
  // Check detection status
  if (detected == false) {
    
    Serial.println("Already detected ?");
    String request = "device="+ sensor_id +"&phase=detection&end";
    String result = sendRequest(request, cc3000, ip);
    
    if(result.startsWith("Device already detected"))
    {
      Serial.println("Device already detected");
      detected = true;
    }
  }
  
   // First readout
  int sensor_value = digitalRead(sensor_pin);
  old_sensor_value = sensor_value;
  
  // End of setup
  Serial.println("Detected:");
  Serial.println(detected);
  Serial.println("Registered:");
  Serial.println(registered);
}

void loop() {
  
  // Detection phase 
  if (registered == false && detected == false)
  {
    Serial.println("Waiting for detection");
    
    String request = "device="+ sensor_id +"&phase=detection&end";
    String result = sendRequest(request, cc3000, ip);
    
    // Sensor detected ?
    if(result.startsWith("Device detected"))
    {
      Serial.println("Device detected");
      detected = true;
    }
  
  // Retry every second
  delay(1000);

  }
  
  // Registration phase 
  if (registered == false && detected == true)
  {
    Serial.println("Waiting for registration");
    String request = "device="+sensor_id+"&phase=registration&end";
    String result = sendRequest(request, cc3000, ip);
  
  // Request received ?  
  if(result.startsWith("Device registered"))
    {
      Serial.println("Sensor Registered");
      registered = true;
    }
  
  // Retry every second
  delay(1000);

  }
  
  // Normal operation
  if (registered == true) {
 
    // Read sensor
    int sensor_value = digitalRead(sensor_pin);
    
    // If the value didn't change, transmit nothing
    if (sensor_value == old_sensor_value) {
      delay(1000);
    }
    
    // Otherwise, connect to server to transmit data
    else {
       if (sensor_value == 1) {
          String request = "device="+sensor_id+"&data=On&phase=receive&end";
          String result = sendRequest(request, cc3000, ip);
       }
       else {
          String request = "device="+sensor_id+"&data=Off&phase=receive&end";
          String result = sendRequest(request, cc3000, ip);
       }
    
    old_sensor_value = sensor_value;
    
    }
  }
  
}

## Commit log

2013-08-08 3d render of motion sensor
    [motion_back.stl, motion_front.stl]
2013-08-08 base added
    [base_back.scad]
2013-08-08 base back modified
    [base_back.scad]
2013-08-09 first version temp case
    [temperature_back.stl, temperature_front.scad, temperature_front.stl]
2013-08-11 primitives integrated for motion sensor
    [motion_back.scad, motion_front.scad, primitives.scad]
2013-08-14 relay sketch added
2013-08-20 schematics added for all modules
    [base_station.fzz, camera_module.fzz, contact_sensor.fzz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]
2013-08-20 fixed camera module
2013-08-20 update camera schematics
    [camera_module.fzz]
2013-08-20 motion sensor sche
2013-08-20 temperature schem
    [temperature_sensor_digital.fzz]
2013-08-20 schem relay
2013-08-20 base schem
    [contact_sensor.fzz]
2013-09-17 major update with PCBs and sketches
    [arduino_basic.sch, motion_back.scad, motion_front.scad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]
2013-09-18 fixes in relay board
    [relay.brd, relay.sch]
2013-09-27 common board added
    [base.brd, base.sch, common_board_smd.brd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]
2013-09-30 repo cleanup
    [arduino_basic.sch, base_back.scad, camera_module.fzz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]
2013-10-01 update smd board
    [common_board_smd.brd, common_board_smd.sch]

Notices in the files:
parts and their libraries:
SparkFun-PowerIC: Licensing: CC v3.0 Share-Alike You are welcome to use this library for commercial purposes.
